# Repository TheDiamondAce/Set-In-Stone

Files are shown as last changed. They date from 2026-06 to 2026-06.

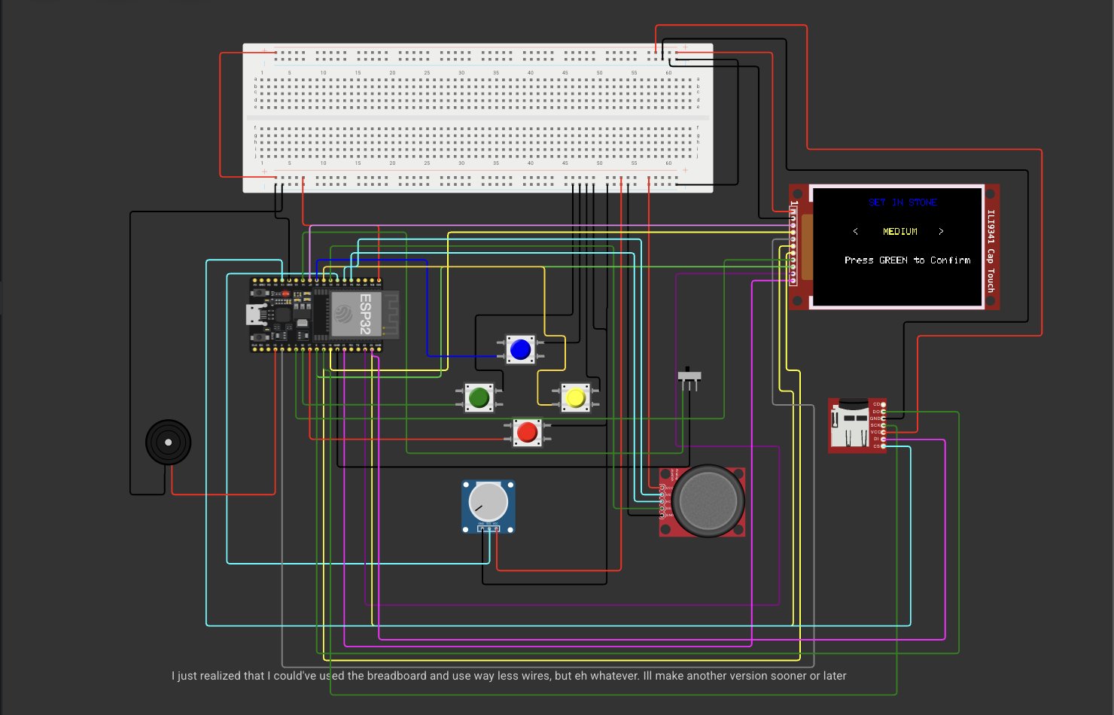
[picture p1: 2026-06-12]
Others/Wiring Diagram.png

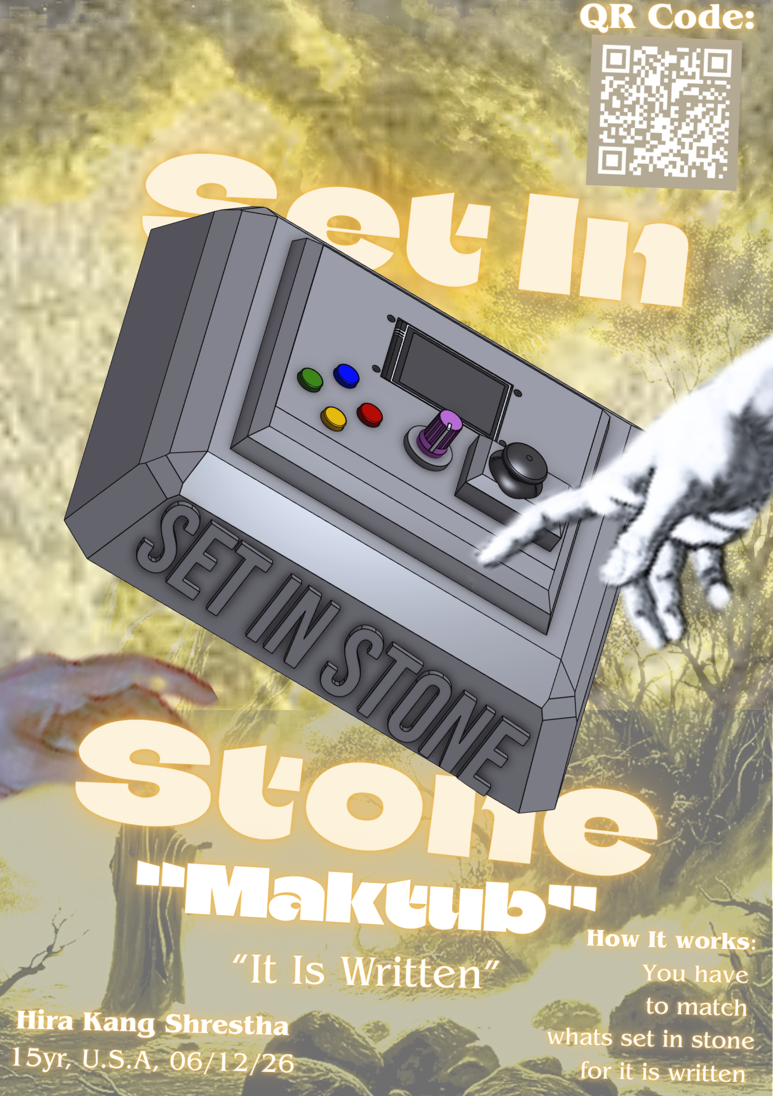
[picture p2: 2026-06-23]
Others/Set In Stone Zine.png

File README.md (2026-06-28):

# Set In Stone

Set In Stone (3)

# Motivation
Starting off with the motivation, I wanted to challenge myself, making something big for my second project, upon which I decided to ultilize my skills of CAD over 2 years on onshape and also my newfound knowledge of C++ hardware coding
I wanted to do a minigame of sorts, learning how modules work and interact with microcontrollers. I realized that most modules use a combination of using eletrical charges to output or input values into code. Which I found to be a revalation suprisingly

# What is this?
This project is a minigame similar to Simon Says and Bop it combined, you have to do multiple inputs to get a point, making it harder and harder as you progress. It is a reaction game of sorts, benefiting the people with great hand to eye coordination

# How to Build?
To build this, you first need to get the pieces as listed in the BOM, you will have to download the code from the Code folder and need to 3D print the enclosure/chassis as well as the button caps. Then, you will need to get the required modules and follow the wiring diagram as shown below here. For the PCB, you will need to first remoe the 3 wires on the left hand of the tft display since you wont need it for the build. Then after you remove it, you will need to solder the modules onto the PCB, however, the parts that you fit to the LID first are the joystick and the display. Then after you connect the PCB to the modules and also to the lid, you will need to get the usb c extension cable and fit it into the usb c gap in the bottom. After, its just a matter of plugging into a power source through the cable, then plug and play!
# What am I proud of?
Most definitely the code first, then the CAD, but not far behind. The reason for this is because I think for the first time, I actually understood the code sorta, and figured out what each thing does, actually using struct functions and enum functions, in an actual way. (Update) Okay, so the first thing I'm proud of now is the PCB as this is the first time i've ever done PCB tinkering, and I'm glad to say, it was a success!
Usually, when I coded, I never really bothered to use such types of functions, but with this project, I realized that, im getting better at coding. For CAD, I really am happy that I managed to get all of the constraints to a precises level to my standards. Also the way I designed it was 
sorta challenging for me at my level.
# What is the next steps?
Im thinking of making it so that there will be more audio and a spritesheet on the display with a mascot, being happy or mad whenever you get something right and wrong. Im also thinking of adding bluetooth audio so that I can implement a simon says mechanic, making it so that on certain cases, you dont press unless the stone says lmao, but not soul says haha.
# Anything else
Nah 
# Ur CAD Diagrams and Wiring?
Oh shoot yeah ur right
# CAD Pictures

## Isometric



## Front



## Back



## Side



# BOM
| Name | Description | Quantity | Price  | Why | Link |
|---|---|---|---|---|---|
| Joystick | A module that uses potentiometers and a stick to measure values | 1 | $8.79  | So you can do stuff to memorize for the minigame | https://www.amazon.com/DKARDU-Dual-axis-Joystick-Control-Breakout/dp/B0B5GLYPLT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 |
| 12mm Button | A tactile switch that either connects a cirucuit or disconnects depending on input | 4 | $12.07 | So you can click stuff to memorize for the minigame | https://www.amazon.com/Uxcell-a11111400ux0132-Momentary-Tactile-Button/dp/B0090VQLDK |
| 12mm Button Caps (Red Green Yellow Blue) | The caps to indentify which button is which (Will be 3D printer most likely) | 4 | $0.00  | To know which button is which. | can 3D print through hackclub or by yourself |
| Potentiometer | A module that uses potentiometers and a stick to measure values through rotation | 1 | $9.99  | Another cool function that gives varation and intresting mechanics | https://www.amazon.com/TWTADE-Adjustable-Potentiometer-Resistance-XH2-54-3P/dp/B082FCRQS2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 |
| TFT LCD 2.4 inch ILI9341 Touch | Display used to show what inputs to press next and as well as score and timer | 1 | $12.39 | To see what inputs to do next and other data | https://www.amazon.com/ACEIRMC-ILI9341-Display-Touch-240X320/dp/B0C4D5S6G5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 |
| -ESP 32 | The Microcontroller that will control all functions of the minigame as well as logic. | 1 | $9.99  | To control the whole minigame and logic | http://amazon.com/HiLetgo-ESP-WROOM-32-Development-Microcontroller-Integrated/dp/B0718T232Z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 |
| Half Breadboard | A module used to have extra ports and have more leeway in circuit connections | 1 | $5.99  | For extra ports to connect GND and PWR and other wires too. | https://www.amazon.com/WWZMDiB-SYB-170-Breadboard-Plates-Multicolored/dp/B09YXQJMTG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 |
| Dupont Female-Male Wires | Used to connect modules to microcontroller and circuits. | ~40 | $6.99  | Bruh, so the whole thing can get some electricity. | https://www.amazon.com/Solderless-Multicolored-Electronic-Breadboard-Protoboard/dp/B09FPJM3L9?th=1 |
| 3D Printer Enclousure. | The host for all modules necessary in the build | 1 | $0.00  | To put all of the modules into one area | can print through hackclub or by yourself with step file |
| M7 Jam Nut | 7mm in diameter Jam nut. (Optional because potentiometer has this.) | 1 | $0.00  | To Screw in the Potentiometer | not necessary since potentiometer link has the jam nut already |
| M4 Screw | 4mm in diameter Screw | 4 | $9.99  | To Screw in the Joystick Module and display. | https://www.amazon.com/mxuteuk-450PCS-Screws-Assortment-Socket/dp/B0CS67BLQJ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 |
| M4 Jam Nut | 4mm in diameter Jam Nut | 4 | $0.00  | ~. ~. ~. ~ | ~~~ (the link above has both the jam nut and screws) |
| M3 Screw | 3mm in diameter Screw for Electronics | 4 | $0.00  | For PCB | ~~~ (the link above has both the jam nut and screws) |
| M3 Jam Nut | To tighten the 3mm screw | 4 | $0.00  | For PCB | ~~~ (the link above has both the jam nut and screws) |
| PCB | A electrical component custom made for a specific task | 1 | $62.32 | So the whole thing can be connected seamlessly if not using a breadboard and jumper wires. | https://www.pcbway.com/orderonline.aspx?outsideid=4bd99289-acd0-49fe-ba78-ffb373cdaed3 |
| THE LINKS USED MIGHT HAVE MULTIPLE PIECES SINCE THEY ARE THE BEST BANG FOR BUCK ON AMAZON.*** | | | | | |
| | TOTAL PRICE= | $138.52  | | | |
| | (MINUS $5.99 if using breadboard and $62.32 IF USING BREADBOARD!!) | | | | |

# Wiring Diagram

## Breadboard Prototype Wiring

Wiring Diagram

## Schematics PCB Diagram



## PCB Footprint Diagaram



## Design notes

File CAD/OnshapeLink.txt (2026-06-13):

Onshape Link:
https://cad.onshape.com/documents/3a4d7bc83de7530c4c0f3050/w/86fc6a0bf872ebef4f94d176/e/49b2cbca54cbe995287650f3

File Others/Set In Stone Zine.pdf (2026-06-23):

## QR Code:

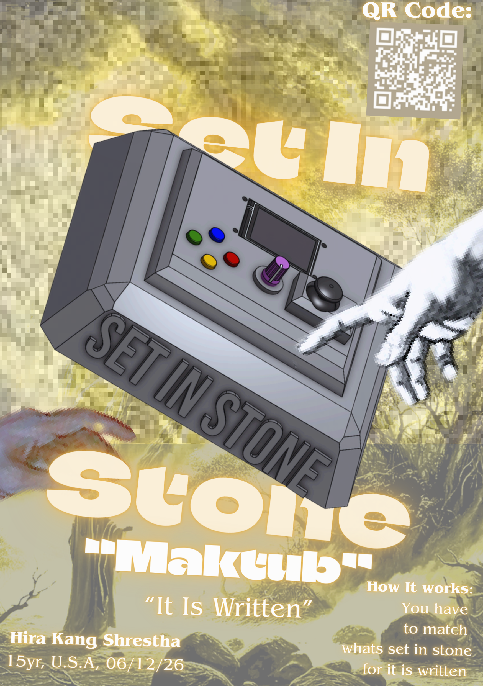
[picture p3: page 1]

# Set In

# Stone

# “It Is Written”

# “Maktub”

Hira Kang Shrestha
15yr, U.S.A, 06/12/26

How It works:
You have
to match
whats set in stone
for it is written

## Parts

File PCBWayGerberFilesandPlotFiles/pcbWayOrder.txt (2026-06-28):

https://www.pcbway.com/orderonline.aspx?outsideid=4bd99289-acd0-49fe-ba78-ffb373cdaed3

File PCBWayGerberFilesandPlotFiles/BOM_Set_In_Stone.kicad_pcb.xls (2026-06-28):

Designator | Quantity | Value | Footprint | Package | MPN | DNP | Mount_Type | Description | KiLib_Generator | Sim.Device | Sim.Type | Sim.Pins | MF | MAXIMUM_PACKAGE_HEIGHT | Price | Check_prices | STANDARD | PARTREV | SnapEDA_Link | MP | MANUFACTURER | Availability | SNAPEDA_PN
BZ1 | 1 | Buzzer | Buzzer_12x9.5RM7.6 |  |  |  | tht | Buzzer, polarized
J1 | 1 | TFT ILI9341 Cap Touch | PinHeader_1x11_P2.54mm_Vertical |  |  |  | tht | Generic connector, single row, 01x11, script generated (kicad-library-utils/schlib/autogen/connector/) | connector/pin_header_socket
J2 | 1 | Joystick | PinSocket_1x05_P2.54mm_Vertical |  |  |  | tht | Generic connector, single row, 01x05, script generated (kicad-library-utils/schlib/autogen/connector/) | connector/pin_header_socket
J3 | 1 | Conn_01x06 | PinSocket_1x06_P2.54mm_Vertical |  |  |  | tht | Generic connector, single row, 01x06, script generated (kicad-library-utils/schlib/autogen/connector/) | connector/pin_header_socket
RV1 | 1 | R_Potentiometer | PinSocket_1x03_P2.54mm_Vertical |  |  |  | tht | Potentiometer | connector/pin_header_socket | R | POT | 1=r0 2=wiper 3=r1
SW1 | 1 | Blue Button | SW_PUSH-12mm |  |  |  | tht | Push button switch, generic, two pins
SW2 | 1 | Green Button | SW_PUSH-12mm |  |  |  | tht | Push button switch, generic, two pins
SW3 | 1 | Yellow Button | SW_PUSH-12mm |  |  |  | tht | Push button switch, generic, two pins
SW4 | 1 | Red_Button | SW_PUSH-12mm |  |  |  | tht | Push button switch, generic, two pins
U1 | 1 | ESP32-DEVKITC-32D | MODULE_ESP32-DEVKITC-32D | None |  |  | tht | WiFi Development Tools (802.11) ESP32 General Development Kit, ESP32-WROOM-32D on the board |  |  |  |  | Espressif Systems | N/A | None | https://www.snapeda.com/parts/ESP32-DEVKITC-32D/Espressif+Systems/view-part/?ref=eda | Manufacturer Recommendations | V4 | https://www.snapeda.com/parts/ESP32-DEVKITC-32D/Espressif+Systems/view-part/?ref=snap | ESP32-DEVKITC-32D | Espressif Systems | In Stock | ESP32-DEVKITC-32D

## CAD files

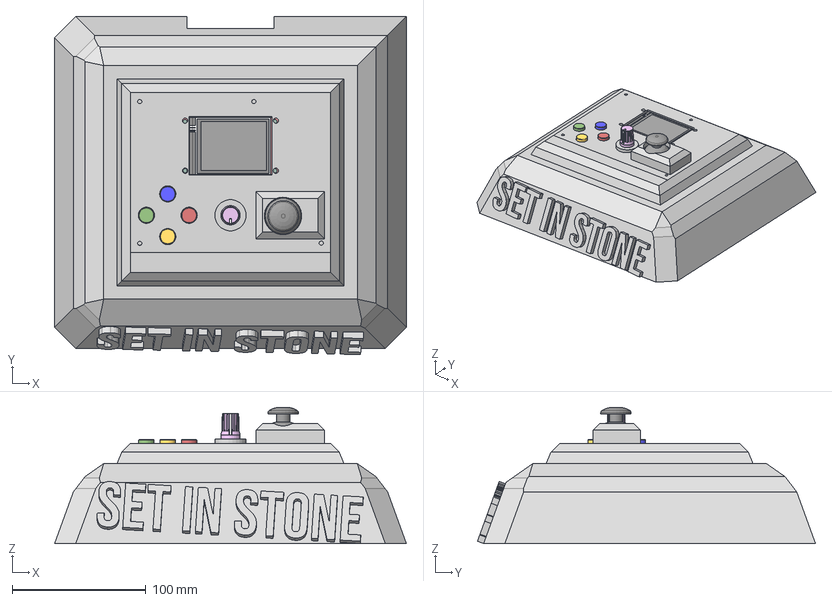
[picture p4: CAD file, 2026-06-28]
CAD/Set In Stone Final Design With PCB.step
263.7 x 253.3 x 102.2 mm
Knob
text x 16
TSSOP-16_L5.0-W4.4-P0.65-LS6.4-BL~TSSOP-16_L5.0-W4.4-H1.0-LS6.4-P0.65 ~HwOR x 30
R0603~R0603~HwOR_2 x 4
R0603~R0603~HwOR_1 x 4
SOT-23-3_L2.9-W1.3-P1.90-LS2.4-BR~SOT-23-3P_L2.9-W1.3-H1.0-LS2.4-P0.9 5~HwOR_1 x 17
R0603~R0603~HwOR_5 x 4
R0603~R0603~HwOR x 4
SOT-23-3_L2.9-W1.3-P1.90-LS2.4-BR~SOT-23-3P_L2.9-W1.3-H1.0-LS2.4-P0.9 5~HwOR x 17
R0603~R0603~HwOR_4 x 4
SD-CARD-SMD_SD-CARD-11P~SD-CARD-SMD_SD-CARD-11P~HwOR x 15
TFT LCD 2.4 inch ILI9341 Touch v3 x 8
CONN-TH_PZ254V-11-14P~CONN-TH_PZ254V-11-14P~HwOR
12mm Push Button Cap x 4
Push Button x 4
Set_In_Stone_PCB
External Case x 4
chroma cap v8 x 2
R0603~R0603~HwOR_3 x 4
Board~HwOR
JoystickLID
C0603~C0603_L1.6-W0.8-H0.8~HwOR_1
Steel Plate x 4
Foundation
M7 � 0.75 NUT
C0603~C0603_L1.6-W0.8-H0.8~HwOR
LID
Base
HDR-TH_4P-P2.54-V-M~HDR-TH_4P-P2.54-M-LI-1X4P~HwOR
board
tactileswitch-short
potentiometer___ x 8
joystickhead___
chip (1) x 43
pcb x 43
boot button
?simsiz v2
en button

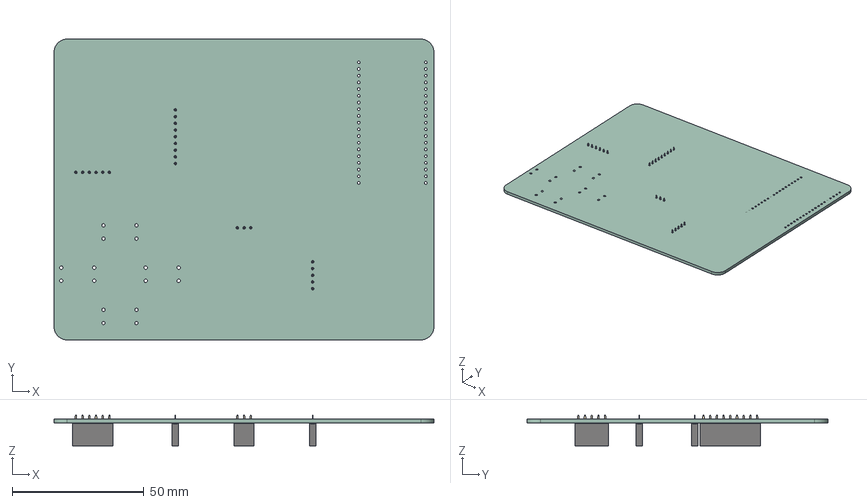
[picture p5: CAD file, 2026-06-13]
PCB-Set-In-Stone-KiCAD/.step
144.0 x 114.0 x 11.6 mm
PinSocket_1x09_P2.54mm_Vertical
PinSocket_1x05_P2.54mm_Vertical
PinSocket_1x06_P2.54mm_Vertical
PinSocket_1x03_P2.54mm_Vertical
Set_In_Stone_PCB

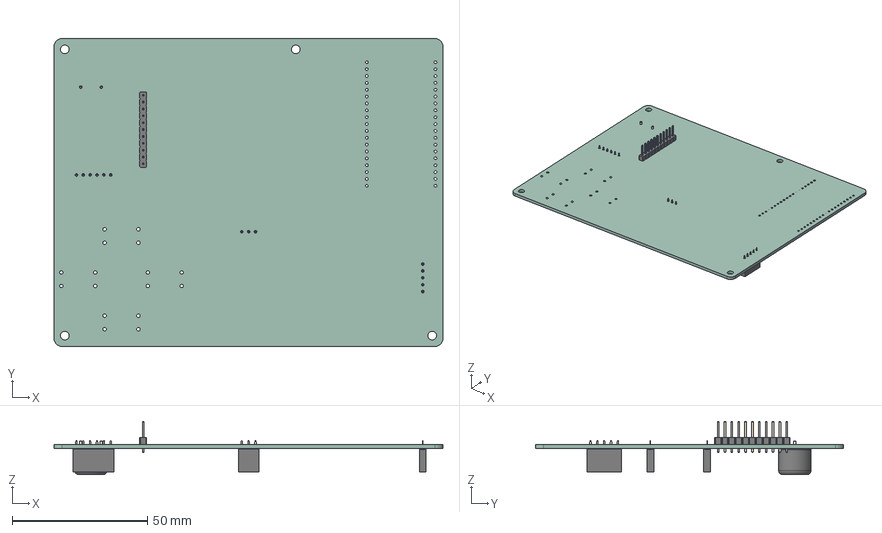
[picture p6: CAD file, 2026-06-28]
CAD/SetInStonePCBFinal.step
144.0 x 114.0 x 19.8 mm
PinHeader_1x11_P2.54mm_Vertical
PinSocket_1x05_P2.54mm_Vertical
PinSocket_1x06_P2.54mm_Vertical
Buzzer_12x9.5RM7.6
PinSocket_1x03_P2.54mm_Vertical
Set_In_Stone_PCB

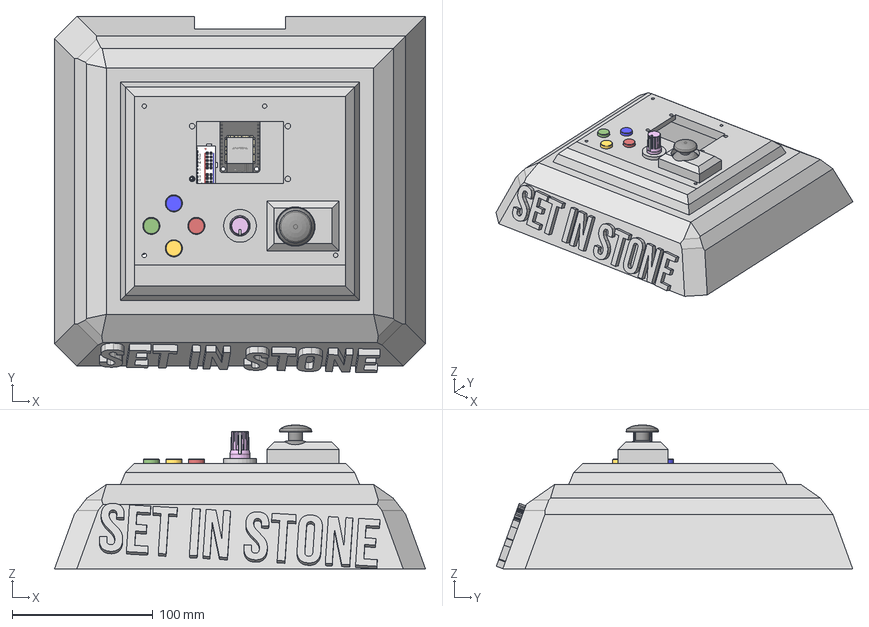
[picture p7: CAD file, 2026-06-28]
CAD/Set In Stone Final Design Without PCB.step
263.7 x 253.3 x 102.2 mm
Knob
External Case x 4
12mm Push Button Cap x 4
Push Button x 4
chroma cap v8 x 2
LID
Base
JoystickLID
Steel Plate x 4
HalfBreadboard x 2
Foundation
board
tactileswitch-short
potentiometer___ x 8
joystickhead___
M7 � 0.75 NUT
chip (1) x 43
pcb x 43
boot button
?simsiz v2
en button

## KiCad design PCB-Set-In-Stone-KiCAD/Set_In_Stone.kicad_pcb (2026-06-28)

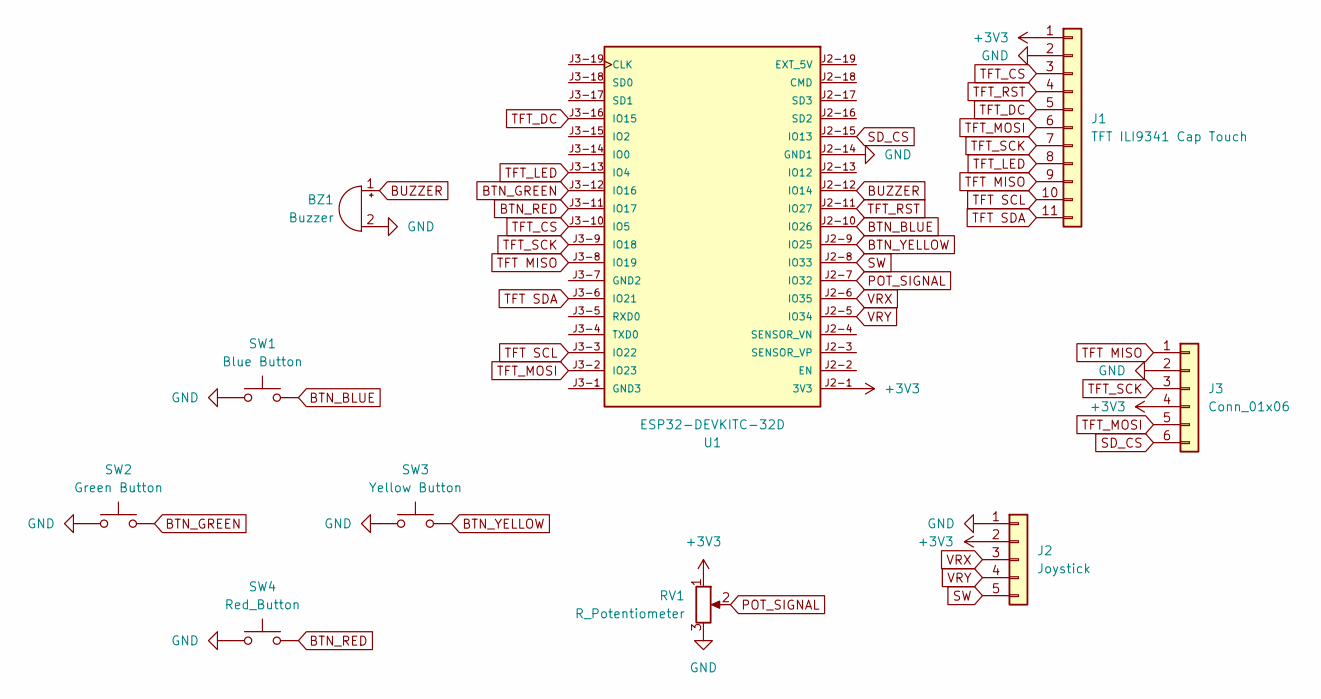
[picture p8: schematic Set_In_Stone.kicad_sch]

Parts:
BZ1: Buzzer; Buzzer_12x9.5RM7.6
J1: TFT ILI9341 Cap Touch; PinHeader_1x11_P2.54mm_Vertical
J2: Joystick; PinSocket_1x05_P2.54mm_Vertical
J3: Conn_01x06; PinSocket_1x06_P2.54mm_Vertical
RV1: R_Potentiometer; PinSocket_1x03_P2.54mm_Vertical
SW1: Blue Button; SW_PUSH-12mm
SW2: Green Button; SW_PUSH-12mm
SW3: Yellow Button; SW_PUSH-12mm
SW4: Red_Button; SW_PUSH-12mm
U1: ESP32-DEVKITC-32D; MODULE_ESP32-DEVKITC-32D; PARTREV V4

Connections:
+3V3: J1.1, J2.2, J3.4, RV1.1, U1.J2-1 (3V3)
BTN_BLUE: SW1.2, U1.J2-10 (IO26)
BTN_GREEN: SW2.2, U1.J3-12 (IO16)
BTN_RED: SW4.2, U1.J3-11 (IO17)
BTN_YELLOW: SW3.2, U1.J2-9 (IO25)
BUZZER: BZ1.1 (+), U1.J2-12 (IO14)
GND: BZ1.2 (-), J1.2, J2.1, J3.2, RV1.3, SW1.1, SW2.1, SW3.1, SW4.1, U1.J2-14 (GND1)
POT_SIGNAL: RV1.2, U1.J2-7 (IO32)
SD_CS: J3.6, U1.J2-15 (IO13)
SW: J2.5, U1.J2-8 (IO33)
TFT MISO: J1.9, J3.1, U1.J3-8 (IO19)
TFT SCL: J1.10, U1.J3-3 (IO22)
TFT SDA: J1.11, U1.J3-6 (IO21)
TFT_CS: J1.3, U1.J3-10 (IO5)
TFT_DC: J1.5, U1.J3-16 (IO15)
TFT_LED: J1.8, U1.J3-13 (IO4)
TFT_MOSI: J1.6, J3.5, U1.J3-2 (IO23)
TFT_RST: J1.4, U1.J2-11 (IO27)
TFT_SCK: J1.7, J3.3, U1.J3-9 (IO18)
VRX: J2.3, U1.J2-6 (IO35)
VRY: J2.4, U1.J2-5 (IO34)

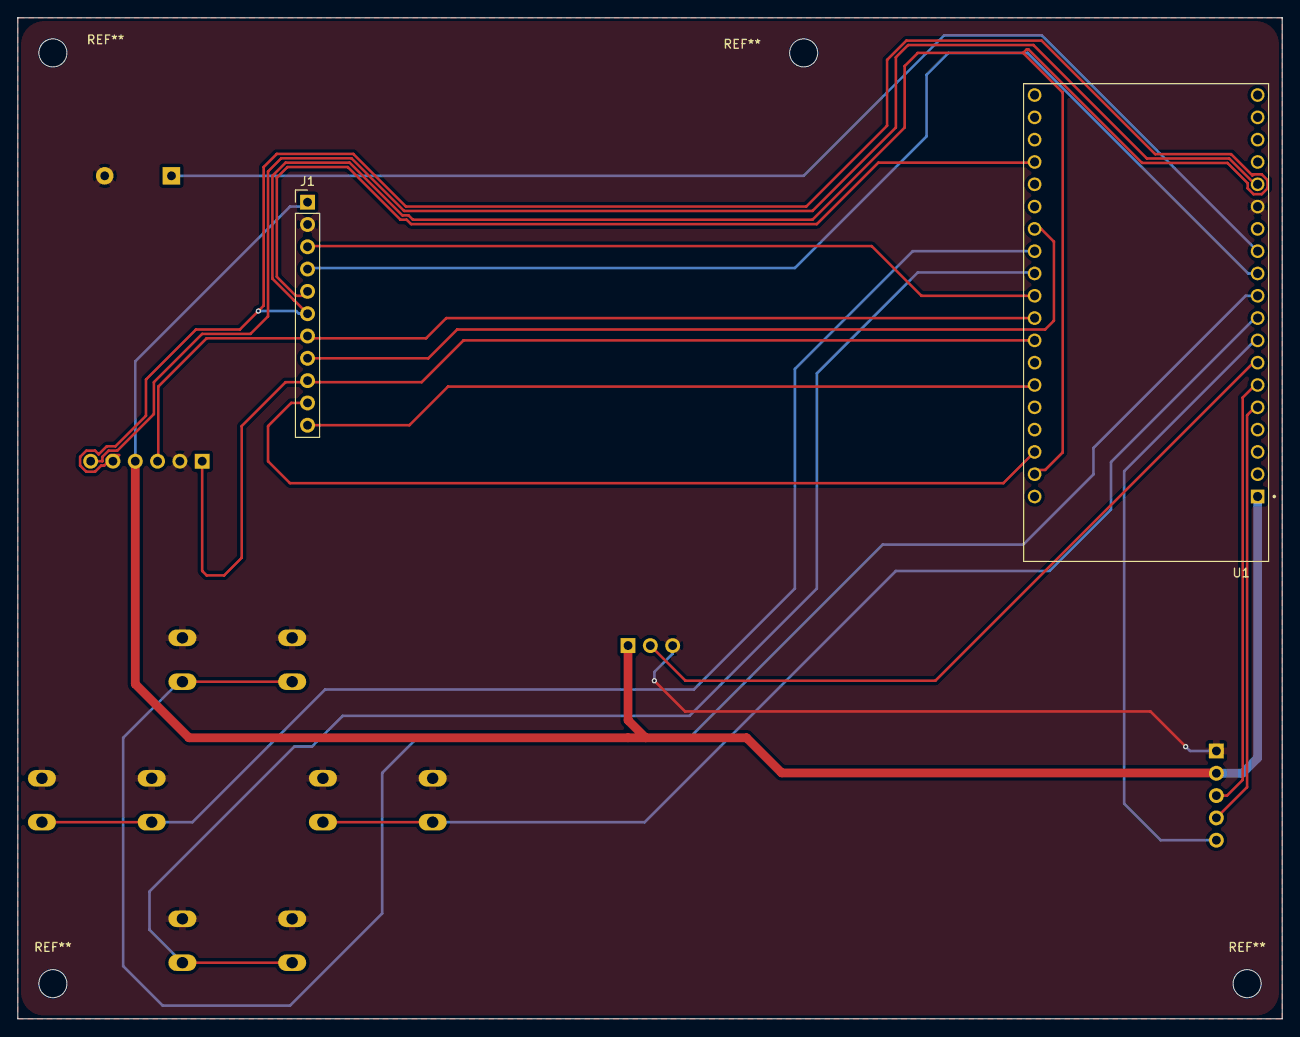
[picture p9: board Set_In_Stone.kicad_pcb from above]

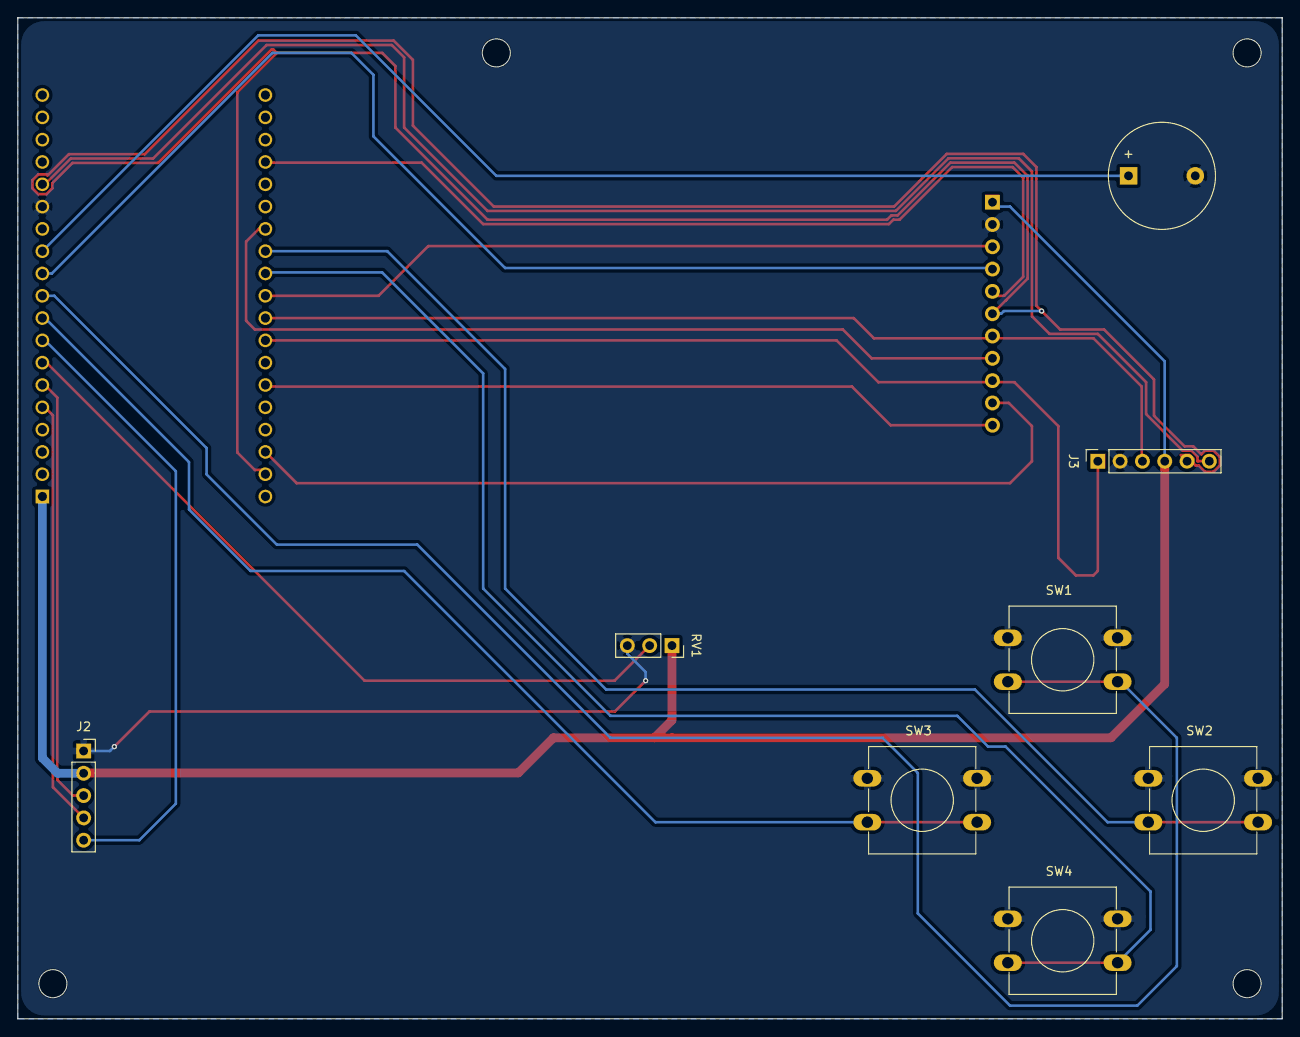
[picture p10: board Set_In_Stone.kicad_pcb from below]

Board: 2 copper layers, 144.0 x 114.0 mm, 10 parts (8 on the bottom side), 21 nets.

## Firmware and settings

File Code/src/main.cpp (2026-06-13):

#include <Arduino.h>
#include <string>
#include <TFT_eSPI.h> // Graphics and font library
#include <BluetoothSerial.h>
#include <BluetoothA2DPSource.h>
#include <SD.h>
#include <SPI.h>

#pragma region Ports

//Button Ports Defintion
#define BUTTONRED 17
#define BUTTONGREEN 16
#define BUTTONBLUE 26
#define BUTTONYELLOW 25

//Buzzer Ports Defintion
#define BUZZER 15

//Display Ports Defintion
#define CS 5
#define RST 27
#define DC 15
#define MOSI 23
#define SCK 18
#define LED 4
#define MISO 19
#define SCL 22
#define SDA 21

//Joystick Ports Defintion
#define VRX 35
#define VRY 34
#define SW 33

//Potentiometer Ports Definition
#define POT 32

//SD Ports Definition
#define CS_SD 13 

#pragma endregion

enum State 
{
    START,
    PLAYING,
    GAME_OVER
};

struct Inputs 
{
    bool buttonRed;
    bool buttonGreen;
    bool buttonBlue;
    bool buttonYellow;
    float joystickX;
    float joystickY;
    bool joystickButton;
    int potentiometerValue;
};

enum Difficulty
{
    EASY,
    MEDIUM,
    HARD
};

struct DifficultySettings
{
    int timeout;
    int inputVariety; 
    int precisionOfAngleError;
};

using namespace std;

//Display Variable
TFT_eSPI tft = TFT_eSPI(); 

//Game Variables
State state = START;
State lastState = GAME_OVER;

//Audio Variables
BluetoothA2DPSource a2dp_source;
File audioFile;
string bluetoothSpeakerName = "Flipper Of TheDiamondAce";
const int FRAME_SIZE_BYTES = sizeof(int16_t)*2;

// Track state adjustments
unsigned long gameTimer = 0;
unsigned long lastActionTime = 0;
unsigned long actionTimer = 0; // Tracks the countdown for the current input step
int score = 0;
int highScore = 0;
short hp = 3;
string inputList[20]; 
int currentInputIndex = 0;
int amountOfInputs = 0; 

// Global tracking variables
Difficulty chosenDifficulty = EASY;
Difficulty lastRenderedDifficulty = HARD; 
int livePotValue = 0;

//Function Prototypes
void checkControls(Inputs inputs);
void displayUpdate();
void gameUpdate(int scoreUpdate, bool gameOver = false);
void gameReset();
void generateNewInputs();
long getCurrentTimeout();

int32_t get_sd_audio_data(Frame *data, int32_t frameCount) {
    if (!audioFile || !audioFile.available()) {
        if (audioFile) {
            audioFile.close(); 
        }
        return 0; 
    }
    size_t bytesRead = audioFile.read((uint8_t*)data, frameCount * FRAME_SIZE_BYTES);
    return bytesRead / FRAME_SIZE_BYTES;
}

DifficultySettings getDifficultySettings(Difficulty difficulty) {
    DifficultySettings settings;
    switch (difficulty) {
        case EASY:
            settings.timeout = 4000; 
            settings.inputVariety = 9; // Cases 0 to 8 (Buttons + Joystick)
            settings.precisionOfAngleError = 40; 
            break;
        case MEDIUM:
            settings.timeout = 3000; 
            settings.inputVariety = 10; // Includes potentiometer option
            settings.precisionOfAngleError = 25; 
            break;
        case HARD:
            settings.timeout = 2000; 
            settings.inputVariety = 10; 
            settings.precisionOfAngleError = 15; 
            break;
    }
    return settings;
}

long getCurrentTimeout() {
    long timeout = getDifficultySettings(chosenDifficulty).timeout - (score * 200);
    if (timeout < 600) timeout = 600; 
    return timeout;
}

void setup() {
    Serial.begin(115200);
    pinMode(BUTTONRED, INPUT_PULLUP);
    pinMode(BUTTONGREEN, INPUT_PULLUP);
    pinMode(BUTTONBLUE, INPUT_PULLUP);
    pinMode(BUTTONYELLOW, INPUT_PULLUP);
    pinMode(VRX, INPUT);
    pinMode(VRY, INPUT);
    pinMode(SW, INPUT_PULLUP);
    pinMode(POT, INPUT);
    pinMode(BUZZER, OUTPUT);
    
    pinMode(LED, OUTPUT);
    digitalWrite(LED, HIGH);
    
    tft.init();
    tft.setRotation(1); 
    tft.fillScreen(TFT_BLACK);

    SPI.begin(18, 5, 23, CS_SD);
    
    if (!SD.begin(CS_SD)) {
        Serial.println("SD Card initialization failed!");
        while (1); 
    }
    
    state = START;
    Serial.println("Setup Complete!"); 
}

void loop() {
    Inputs inputs;
    checkControls(inputs);

    switch (state) {
        case START:
            break;
            
        case PLAYING: {  
            long currentTimeout = getCurrentTimeout(); 

            if (millis() - actionTimer >= currentTimeout) {
                hp--;
                currentInputIndex = 0; 
                
                digitalWrite(BUZZER, HIGH); 
                delay(1000); 
                digitalWrite(BUZZER, LOW);

                actionTimer = millis(); 
                
                if (hp <= 0) {
                    gameUpdate(0, true);
                }
            }
            break;
        } 
            
        case GAME_OVER:
            highScore = max(score, highScore);
            break;
    }

    displayUpdate();
    delay(20); 
}

void gameUpdate(int scoreUpdate, bool gameOver) 
{
    score += scoreUpdate;

    if (gameOver) {
        state = GAME_OVER;
        tft.fillScreen(TFT_BLACK); 
    } else {
        state = PLAYING;
    }
}

void displayUpdate() 
{
    if (state != lastState) {
        tft.fillScreen(TFT_BLACK); 
        tft.setTextSize(2);

        if (state == START) {
            tft.setTextColor(TFT_BLUE, TFT_BLACK);
            tft.drawString("SET IN STONE", 85, 20);
            tft.setTextColor(TFT_WHITE, TFT_BLACK);
            tft.drawString("<              >", 50, 80);
            tft.drawString("Press GREEN to Confirm", 35, 140);
            lastRenderedDifficulty = HARD; 
        }
        else if (state == GAME_OVER) {
            tft.setTextColor(TFT_RED, TFT_BLACK);
            tft.drawString("GAME OVER", 110, 50);
            digitalWrite(BUZZER, HIGH); 
            delay(500);
            digitalWrite(BUZZER, LOW); 
            delay(500);
            digitalWrite(BUZZER, HIGH); 
            delay(500);
            digitalWrite(BUZZER, LOW); 
            delay(500);
            tft.setTextColor(TFT_WHITE, TFT_BLACK);
            tft.drawString("Press GREEN to Retry", 45, 120);
            
            tft.drawString("HP: 0 ", 10, 10);
            tft.drawString("Score: ", 110, 10);
            tft.drawNumber(score, 180, 10);
        }
        else if (state == PLAYING) {
            tft.setTextColor(TFT_BLUE, TFT_BLACK);
            tft.drawString("HP:", 10, 10);
            tft.drawString("Score:", 100, 10);
            tft.drawString("High:", 210, 10);

            tft.setTextColor(TFT_WHITE, TFT_BLACK);
            tft.drawString("ACTION TO DO:", 20, 65);
            tft.drawString("STEPS LEFT:", 20, 122); 
            tft.drawRect(58, 148, 204, 14, TFT_WHITE); 
        }
        
        lastState = state; 
        return; 
    }

    if (state == START && chosenDifficulty != lastRenderedDifficulty) {
        tft.setTextSize(2);
        tft.setTextColor(TFT_YELLOW, TFT_BLACK);
        char diffBuf[20];
        string diffStr = "EASY";
        if (chosenDifficulty == MEDIUM) diffStr = "MEDIUM";
        if (chosenDifficulty == HARD) diffStr = "HARD";
        sprintf(diffBuf, "%-8s", diffStr.c_str());
        tft.drawString(diffBuf, 115, 80);
        lastRenderedDifficulty = chosenDifficulty;
    }

    if (state == PLAYING) {
        static unsigned long lastRenderTime = 0;
        if (millis() - lastRenderTime < 30) return;
        lastRenderTime = millis();

        tft.setTextSize(2);
        tft.setTextColor(TFT_WHITE, TFT_BLACK); 

        tft.drawNumber(hp, 45, 10);
        
        char scoreBuf[10];
        sprintf(scoreBuf, "%-3d", score);
        tft.drawString(scoreBuf, 170, 10);
        tft.drawNumber(highScore, 270, 10);

        tft.setTextColor(TFT_YELLOW, TFT_BLACK);
        string targetAction = inputList[currentInputIndex];
        
        // INTERCEPT ENCODED STRINGS TO PRINT A CLEAN LABEL
        string cleanDisplayAction = targetAction;
        if (targetAction.rfind("pot:", 0) == 0) {
            cleanDisplayAction = "TURN DIAL!";
        }
        
        char actionBuf[25];
        sprintf(actionBuf, "%-16s", cleanDisplayAction.c_str()); 
        tft.drawString(actionBuf, 40, 95);

        tft.setTextColor(TFT_GREEN, TFT_BLACK);
        int stepsRemaining = amountOfInputs - currentInputIndex;
        if (stepsRemaining < 0) stepsRemaining = 0;
        tft.drawNumber(stepsRemaining, 160, 122);

        // --- DYNAMIC POTENTIOMETER BRACKET VISUALIZER ---
        if (targetAction.rfind("pot:", 0) == 0) {
            int firstColon = targetAction.find(':');
            int secondColon = targetAction.find(':', firstColon + 1);
            int targetMin = stoi(targetAction.substr(firstColon + 1, secondColon - firstColon - 1));
            int targetMax = stoi(targetAction.substr(secondColon + 1));

            tft.setTextSize(1);
            tft.setTextColor(TFT_BLUE, TFT_BLACK);
            tft.drawString("0deg", 55, 185);
            tft.drawString("270deg", 235, 185);
            tft.drawRect(58, 170, 204, 12, TFT_BLUE); 

            // Clear inner data canvas workspace
            tft.fillRect(59, 171, 202, 10, TFT_BLACK);

            // Calculate bracket margins and map from 0-270 degrees into 0-200 pixels width
            int bracketMinX = 60 + (targetMin * 200) / 270;
            int bracketMaxX = 60 + (targetMax * 200) / 270;
            int bracketWidth = bracketMaxX - bracketMinX;
            if (bracketWidth < 6) bracketWidth = 6;

            // Draw target bracket zone
            tft.fillRect(bracketMinX, 171, bracketWidth, 10, TFT_YELLOW);

            // Compute current cursor location based on the live reading
            float currentAngle = (livePotValue * 270.0) / 4095.0;
            int cursorX = 60 + (currentAngle * 200) / 270;
            if (cursorX > 260) cursorX = 260;
            if (cursorX < 60) cursorX = 60;

            // Turn indicator green if it is sitting inside the objective bracket
            if (cursorX >= bracketMinX && cursorX <= bracketMaxX) {
                tft.fillRect(cursorX - 2, 171, 5, 10, TFT_GREEN);
            } else {
                tft.fillRect(cursorX - 2, 171, 5, 10, TFT_CYAN);
            }
            tft.setTextSize(2); 
        } else {
            tft.fillRect(55, 170, 215, 25, TFT_BLACK); 
        }

        long currentTimeout = getCurrentTimeout();
        long elapsed = millis() - actionTimer;
        long remaining = currentTimeout - elapsed;
        if (remaining < 0) remaining = 0;

        int barWidth = (remaining * 200) / currentTimeout;
        
        tft.fillRect(60, 150, barWidth, 10, TFT_GREEN); 
        tft.fillRect(60 + barWidth, 150, 200 - barWidth, 10, TFT_BLACK); 
    }
}

void gameReset()
{
    score = 0;
    state = PLAYING;
}

void checkControls(Inputs inputs)
{
    inputs.buttonRed = !digitalRead(BUTTONRED);
    inputs.buttonGreen = !digitalRead(BUTTONGREEN);
    inputs.buttonBlue = !digitalRead(BUTTONBLUE);
    inputs.buttonYellow = !digitalRead(BUTTONYELLOW);
    inputs.joystickX = analogRead(VRX)/2048.0 - 1;
    inputs.joystickY = analogRead(VRY)/2048.0 - 1;
    inputs.joystickButton = !digitalRead(SW);
    inputs.potentiometerValue = analogRead(POT);

    livePotValue = inputs.potentiometerValue; 

    string currentInput = "";
    if (inputs.buttonRed) currentInput = "buttonRed";
    else if (inputs.buttonGreen) currentInput = "buttonGreen";
    else if (inputs.buttonBlue) currentInput = "buttonBlue";
    else if (inputs.buttonYellow) currentInput = "buttonYellow";
    else if (inputs.joystickButton) currentInput = "joystickButton";
    else if (inputs.joystickX > 0.5) currentInput = "joystickRight";
    else if (inputs.joystickX < -0.5) currentInput = "joystickLeft";
    else if (inputs.joystickY > 0.5) currentInput = "joystickUp";
    else if (inputs.joystickY < -0.5) currentInput = "joystickDown";

    // CHECK ENCODED POTENTIOMETER STRINGS FOR ACTIVE MATCH
    string expectedInput = inputList[currentInputIndex];
    if (expectedInput.rfind("pot:", 0) == 0) {
        int firstColon = expectedInput.find(':');
        int secondColon = expectedInput.find(':', firstColon + 1);
        int targetMin = stoi(expectedInput.substr(firstColon + 1, secondColon - firstColon - 1));
        int targetMax = stoi(expectedInput.substr(secondColon + 1));
        
        float currentAngle = (inputs.potentiometerValue * 270.0) / 4095.0;
        if (currentAngle >= targetMin && currentAngle <= targetMax) {
            currentInput = expectedInput; 
        }
    }

    static bool readyForInput = true;
    static bool choseDifficultyState = false; 

    if (currentInput != "" && readyForInput && currentInput.rfind("pot:", 0) != 0) {
        Serial.print("Button Detected: ");
        Serial.println(currentInput.c_str());
    }

    // =========================================================================
    // 3. MENU & GAME OVER CONTROLLER
    // =========================================================================
    if (state == START) {
        
        if (currentInput == "joystickRight" && readyForInput && !choseDifficultyState) {
            readyForInput = false;
            int nextDiff = (int)chosenDifficulty + 1;
            if (nextDiff > 2) nextDiff = 0;
            chosenDifficulty = (Difficulty)nextDiff;
        }
        
        if (currentInput == "joystickLeft" && readyForInput && !choseDifficultyState) {
            readyForInput = false;
            int prevDiff = (int)chosenDifficulty - 1;
            if (prevDiff < 0) prevDiff = 2;
            chosenDifficulty = (Difficulty)prevDiff;
        }

        if (currentInput == "buttonGreen" && readyForInput) {
            Serial.println("Difficulty Confirmed! Starting Game...");
            readyForInput = false; 
            choseDifficultyState = true;
            
            DifficultySettings settings = getDifficultySettings(chosenDifficulty);

            hp = 3;
            score = 0;
            amountOfInputs = 0;
            currentInputIndex = 0;
            for (int i = 0; i < 20; i++) {
                inputList[i] = "";
            }

            generateNewInputs();       
            state = PLAYING;           
            tft.fillScreen(TFT_BLACK); 
            actionTimer = millis(); 
        }
        
        if (currentInput == "") {
            readyForInput = true;
            choseDifficultyState = false; 
        }
        return; 
    }
    if (state == GAME_OVER) {
        if (currentInput == "buttonGreen" && readyForInput) {
            Serial.println("Starting Over! Returning to Difficulty Selection...");
            choseDifficultyState = false; // Reset difficulty choice to allow re-selection    
            
            // FIX: Lock input here to prevent the button press from bleeding into the next screen!
            readyForInput = false;  
            
            state = START;           
        }
        if (currentInput == "") {
            readyForInput = true;
        }
        return; 
    }


    // =========================================================================
    // 4. ACTIVE GAMEPLAY INPUT PROCESSING ENGINE
    // =========================================================================
    if (currentInput == "")
    {
        readyForInput = true;
    }
    else if (readyForInput)
    {
        readyForInput = false; 

        if (currentInput == expectedInput) {
            currentInputIndex++;
            actionTimer = millis(); 

            if (audioFile) {
                audioFile.close(); 
            }
            audioFile = SD.open("/rightanswer.mp3", FILE_READ);

            Serial.println("Correct Input! Playing Audio!");

            if (currentInputIndex >= amountOfInputs) {
                currentInputIndex = 0;
                gameUpdate(1);
                generateNewInputs();
            }
        }
        else 
        {
            hp--;
            currentInputIndex = 0; 
            
            digitalWrite(BUZZER, HIGH); 
            delay(1000); 
            digitalWrite(BUZZER, LOW);

            actionTimer = millis(); 
            
            if (hp <= 0) {
                gameUpdate(0, true);
            }
        }
    }
}

void generateNewInputs() 
{
    DifficultySettings settings = getDifficultySettings(chosenDifficulty);
    int randomInput = random(0, settings.inputVariety);
    
    switch(randomInput) 
    {
        case 0: inputList[amountOfInputs] = "buttonRed"; break;
        case 1: inputList[amountOfInputs] = "buttonGreen"; break;
        case 2: inputList[amountOfInputs] = "buttonBlue"; break;
        case 3: inputList[amountOfInputs] = "buttonYellow"; break;
        case 4: inputList[amountOfInputs] = "joystickUp"; break;
        case 5: inputList[amountOfInputs] = "joystickDown"; break;
        case 6: inputList[amountOfInputs] = "joystickLeft"; break;
        case 7: inputList[amountOfInputs] = "joystickRight"; break;
        case 8: inputList[amountOfInputs] = "joystickButton"; break;
        case 9: {
            int errorWindow = settings.precisionOfAngleError;
            int randomAngleMin = random(0, 270 - errorWindow);
            int randomAngleMax = randomAngleMin + errorWindow;
            
            // Encode targets directly inside the execution register array
            inputList[amountOfInputs] = "pot:" + to_string(randomAngleMin) + ":" + to_string(randomAngleMax);
        }
        break; 
    }
    amountOfInputs++;
}

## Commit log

2026-06-09 made foundational prototype of Set In Stone
    I got the main.cpp file as well as the wiring diagram from wokwi to consider this a first polished prototype of Set In Stone.
2026-06-10 Added Difficulty Menu To Minigame
    In this update, I added a difficulty bar which allows you to select easy medium hard, which will affect the timer limit.
2026-06-10 version with buzz() and potentiometer visually made by me
    [main.cpp]
2026-06-12 Organizing and Adding Final Stuff
    In this update, i have included the CAD Folder, put the code in a dedicated folder, and added the zine and the wiring diagram.
    [BOM.csv]
2026-06-12 Update README with build instructions for minigame
    Added a section on how to build the minigame, detailing required pieces and assembly instructions.
2026-06-13 Made PCB of Set In Stone
    In this update I decided to make the set in stone PCB as I realized this is a pretty complex project so why not make it more complex to get burnout pathway lmao. Jokes aside, proud of my first PCB ever!!
    [Set_In_Stone-B_Cu.gbr, Set_In_Stone-B_Mask.gbr, Set_In_Stone-B_Paste.gbr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]
2026-06-13 Made finishing touches to PCB
    In this update, I made the final touches for the PCB of the Set In Stone project.
    [.step, SetInStonePCB.step, Set_In_Stone.kicad_pcb]
2026-06-13 Update README with new wiring and PCB diagrams
    Added new sections for breadboard prototype wiring, schematics PCB diagram, and PCB footprint diagram.
2026-06-13 Updated BOM
    Added PCB and M3 Screw Components to the BOM list
    [BOM.csv]
2026-06-17 Updated B.O.M and added high quality PDF
    This update is to revise my project so that I can get it approved, I have made it so that there are links for the people who want to rebuild my project from scratch and also a pdf of the zine so that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
    [BOM.csv]
2026-06-17 Added gitingore for kicad
2026-06-17 Made Wires Bigger and Made PCBWAY GERBER FILES
    In this update, I redid the routing for the wires slightly so that there isnt redudant wires hopefully as well as increase the wire thickness for the general wiring as well as for the VCC which is th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
    [BOM_Set_In_Stone.kicad_pcb.xls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]
2026-06-17 Add new images to README for PCB diagrams
    Added new images for PCB schematics and footprint diagrams.
2026-06-17 Added Redesigned CAD and also PCB
    In this update I added the CAD and PCB files for the project Set In Stone. I will now turn my project in for review
    [Set In Stone Final Design With PCB.step, SetInStonePCBFinal.step]
2026-06-23 Update Set In Stone zine assets and .DS_Store
    Replace Set In Stone Zine PDF and PNG with updated versions. Refresh .DS_Store files in PCB-Set-In-Stone-KiCAD and PCBWayGerberFilesandPlotFiles directories (macOS Finder metadata changes).
2026-06-28 Fixed bugs need to be adressed
    In this update, you know whats up.
    [BOM.csv, BOM_Set_In_Stone.kicad_pcb.xls, Set In Stone Final Design With PCB.step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]
